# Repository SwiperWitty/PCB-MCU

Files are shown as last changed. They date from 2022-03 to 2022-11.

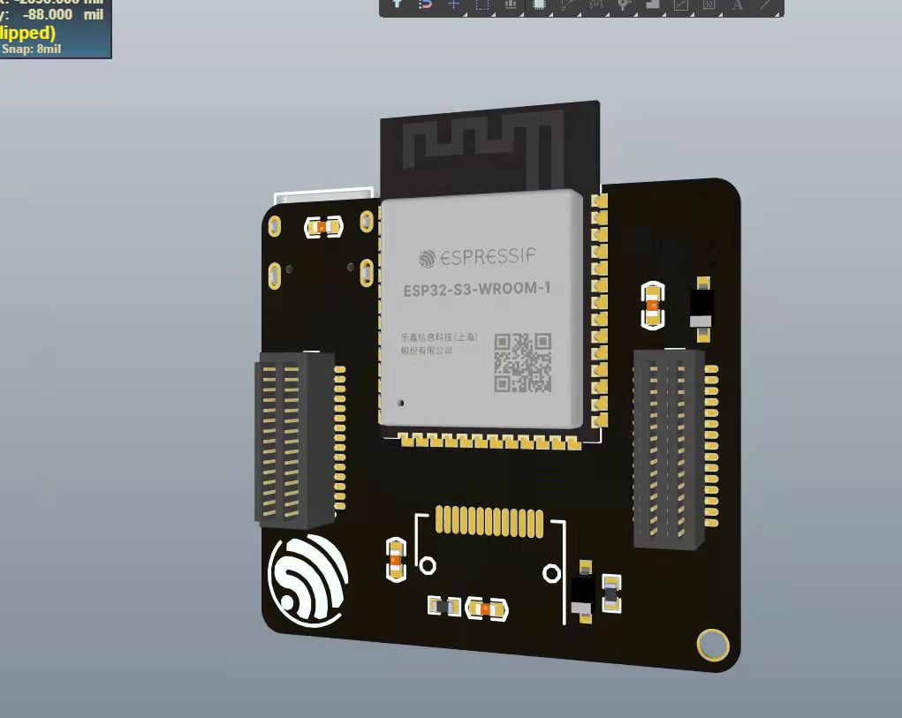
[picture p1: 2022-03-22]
ESP32-S3-HardWare/渲染/ad.jpg

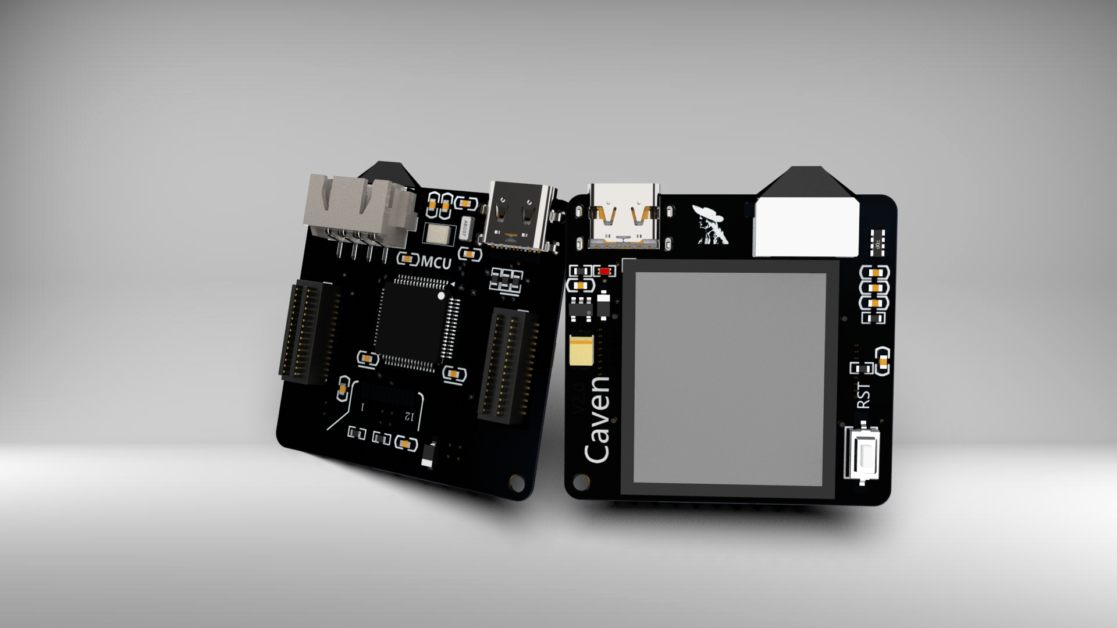
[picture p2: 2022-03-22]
Cavendish/渲染/Caven.jpg

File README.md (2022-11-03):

# PCB-MCU

**MCU-Core board**

# Cavendish(卡文迪许)

STM32 -> 3.0 & 3.14 CORE Software in [here](https://github.com/SwiperWiity/Core-STM32) !

- ##  STM32

#### STM32F103RCT6/GD32

##### Cavendish-ARM	V2.0

Caven

##### Cavendish-ARM	V3.0



##### Cavendish-ARM	V3.14



#### STM32F405RET6

Same as above !

- ## ESP32

#### ESP32-S3

Cavendish-ESP	V1.0



# other：

## PCB-C51



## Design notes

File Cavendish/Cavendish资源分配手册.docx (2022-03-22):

# Cavendish 硬件资源分配手册V2.0

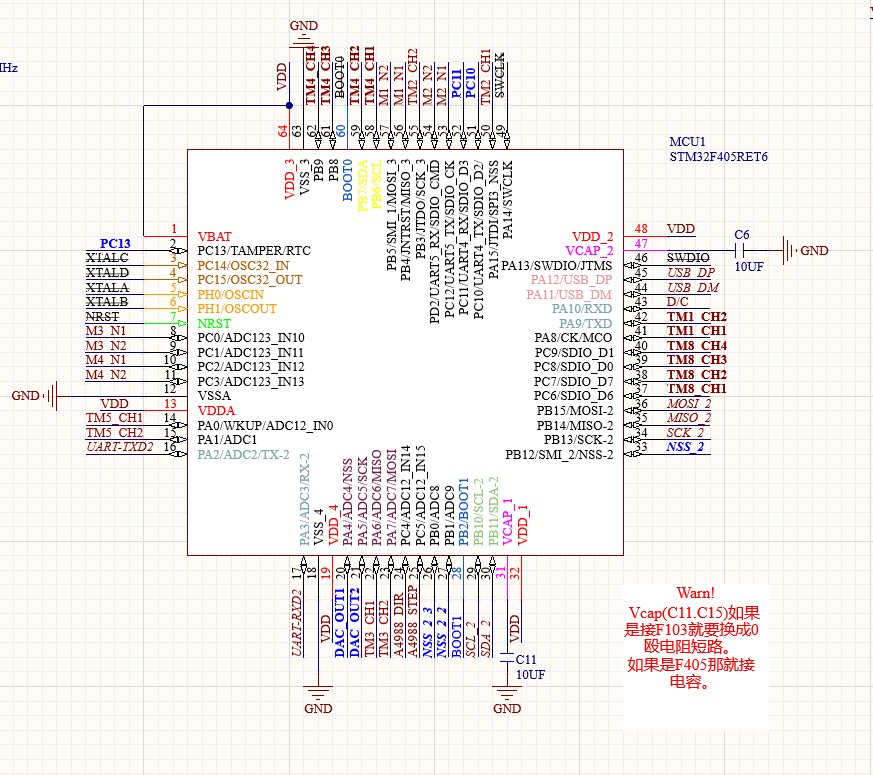
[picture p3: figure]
4f4f9511edc25ea571e4639c8b510fe
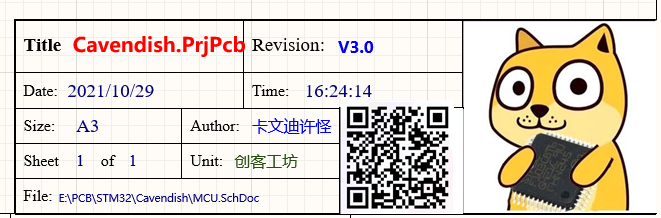
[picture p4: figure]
b53caab79645a7834c044930e13f0a2

目录

Cavendish 硬件资源分配手册V2.0 1

1. LCD 3

2. KEY 5

3. TIME 6

4. UART 8

5. SPI 9

6. USB 10

7. I2C 11

8. ADC 12

9. DAC （和ADC共用） 13

10. 步进电机 14

11. 电机组合 15

## Cavendish STM32F103RCT6/RBT6

### 1. LCD

硬件设备LCD，使用硬件的SPI2，其中：

PA10(D/C) PB12(CS) PB13(SCLK) PB15 (MOSI)

以上GPIO均不可除LCD功能以外使用！（CS可以极限驱动73HC595）

#### 1. RES

不占用GPIO,使用硬件上电复位（需要在MCU上电后等待20MS）

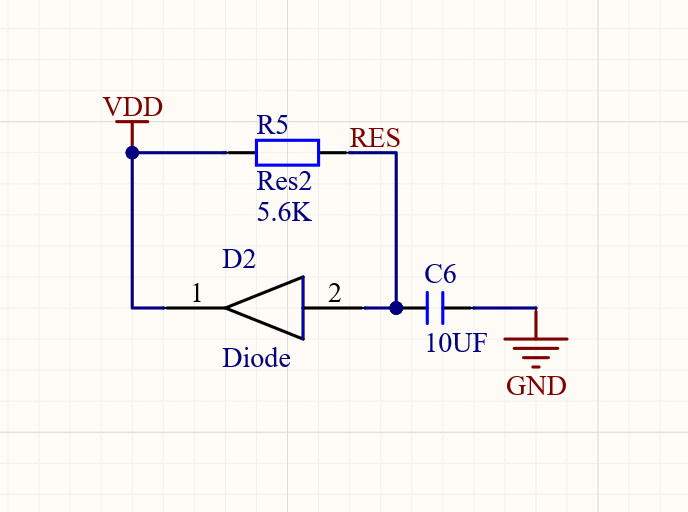
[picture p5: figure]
cd68124e201493866216ad20c528cc5

#### 2. SPI_CS(NSS-2)

PB12

#### 3. SPI_SCL(SCK-2)

PB13

#### 4. SPI_DC（未引到Pin）

PA10(占用UART1的RXD)，所以本设计如果要使用UART1需要重映射。

#### 5. SPI_MOSI

PB15

### 2. KEY

#### KEY0

PC13 触摸按键

#### 自由IO

PC10

PC11

### 3. TIME

#### 1. PWM

通常使用TIM1和TIM8高级定时器做为PWM基础时钟。

##### TIM4

通常作为控制舵机的PWM。

PB6 Channel 1

PB7 Channel 2

PB8 Channel 3

PB9 Channel 4

##### TIM8

通常为直流有刷电机调试PWM。

PC6 Channel 1

PC7 Channel 2

PC8 Channel 3

PC9 Channel 4

#### 2. Capture(编码器)

一般用在读取电机转速、编码按键（相当于鼠标）

##### TIM1

PA8 Channel 1

PA9 Channel 2

##### TIM2

PA15 Channel 1

PB3 Channel 2

##### TIM3

PA6 Channel 1

PA7 Channel 2

##### TIM5

PA0 Channel 1

PA1 Channel 2

### 4. UART

#### 1. 串口2

PA2 TXD

PA3 RXD

#### 2. 串口3 重映射（串口4）

PC10 TXD

PC11 RXD

### 5. SPI

只提供SPI2：

PB15 MOSI

PB14 MISO

PB13 SCLK

PB12 NSS (LCD)

PB1 NSS2

PB0 NSS3 (BZZ)

### 6. USB

PA11 USB_DM

PA12 USB_DP

### 7. I2C

只有I2C-2，有时也用于超声波（需要改接口）

PB11 SDA

PB12 SCL

### 8. ADC

PA4 ADC4

PA5 ADC5

### 9. DAC （和ADC共用）

PA4 OUT1

PA5 OUT2

### 10. 步进电机

DIR PC4

STEP PC5

### 11. 电机组合

#### 1. Motor 1

TIM8- Channel 1

编码 Tim2

方向控制 PB4 PB5(不分AB)

#### 2. Motor 2

TIM8- Channel 2

编码 Tim1

方向控制 PC12 PD2(不分AB)

#### 3. Motor 3（Only Reptile）

TIM8- Channel 3

编码 Tim3 (Type 底板为编码按键)

方向控制 PC0 PC1(不分AB)

#### 4. Motor 4（Only Reptile）

TIM8- Channel 4

编码 Tim5

方向控制 PC2 PC3(不分AB)

## Cavendish STM32F405RET6

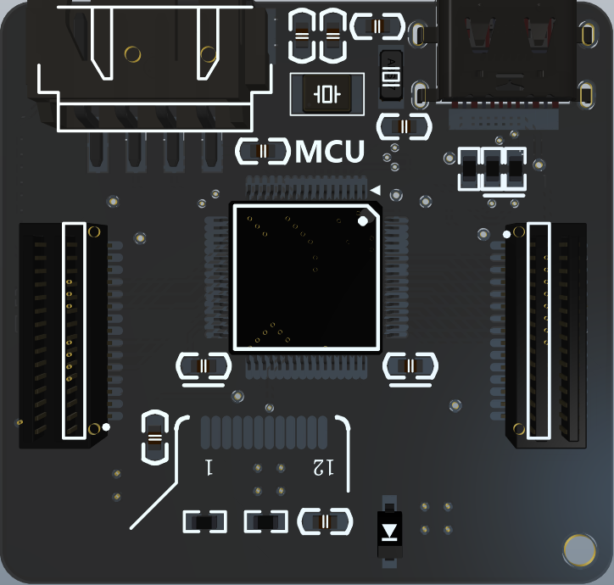
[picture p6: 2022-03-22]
Cavendish/渲染/back.png

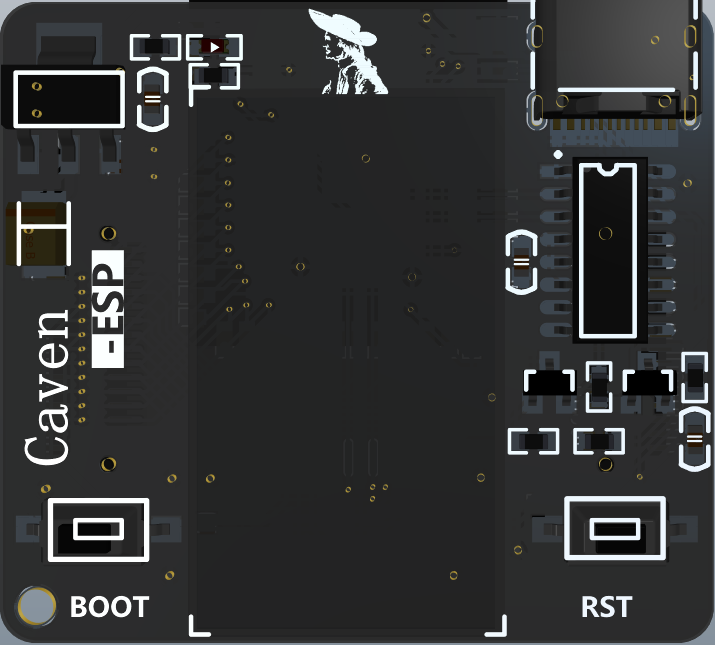
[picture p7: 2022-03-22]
ESP32-S3-HardWare/渲染/f.png

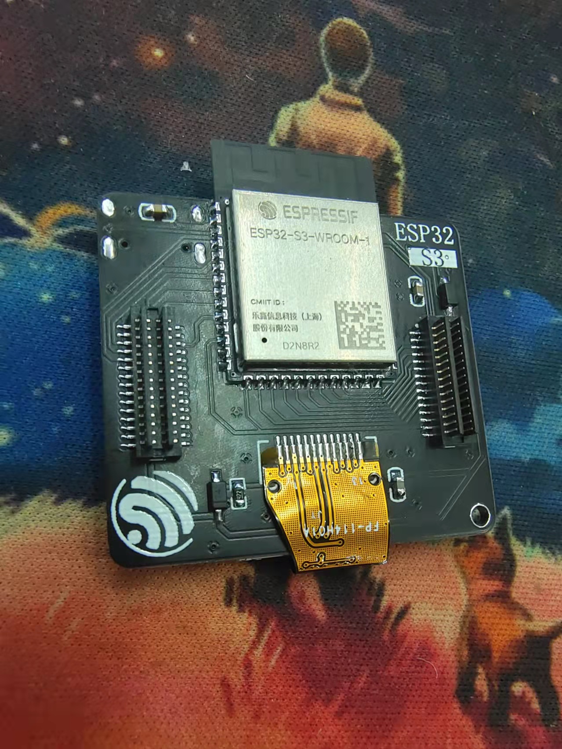
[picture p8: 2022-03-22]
ESP32-S3-HardWare/渲染/b.jpg

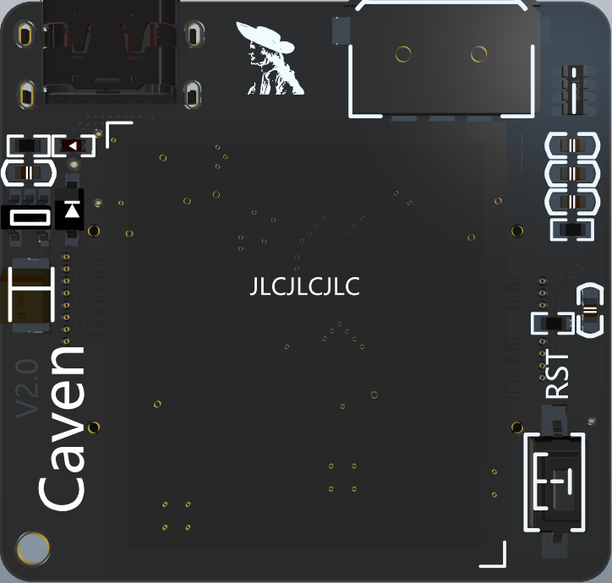
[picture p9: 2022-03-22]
Cavendish/渲染/frist.png

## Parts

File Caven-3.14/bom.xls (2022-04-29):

name |  |  |  |  |  |  |  |  |  |  |  | 0
Bill of Materials for PCB Document [Copy of PCB1.PcbDoc]
卡文迪许 |  |  |  |  |  |  |  |  | 联系方式：13226348320
test 2022-04-24 (49-/-54)
序号 | 器件 | 封装 | 单机用量 | 位号 | 型号 |  | 规格描述 | 总用量 |  | 单价 | 趋势 | 小计
# | Comment | Footprint | Quantity | Designator | Description |  | taobao | NUM
1 | 100NF | CAP_0603 | 6 | C1, C2, C6, C7, C13, C15 | CAP 12~50V | _ |  |  |  |  |  | 0
2 | 100UF | CAP_3216_A | 2 | C3, C4 | CAP 6~12V 钽电容 | _ |  |  |  |  |  | 0
1 | 10UF | CAP_0603 | 2 | C5, C8 | CAP 12~50V | _ |  |  |  |  |  | 0
2 | 10PF | CAP_0603 | 2 | C9, C10 | CAP 12~50V | _ |  |  |  |  |  | 0
1 | 22PF | CAP_0603 | 3 | C11, C12, C14 | CAP 12~50V | _ |  |  |  |  |  | 0
2 | 4.7UF | CAP_0603 | 1 | C16 | CAP 12~50V | _ |  |  |  |  |  | 0
1 | Type-C | USB-TYPE-C_16A | 1 | COM1 | USB | _ |  |  |  |  |  | 0
2 | B5819W | DIODE_SOD123 | 1 | D1 | Diode_肖特基/二极管 | _ |  |  |  |  |  | 0
1 | 1N4148 | DIODE_SOD123 | 1 | D2 | Diode_肖特基/二极管 | _ |  |  |  |  |  | 0
2 | FUSE | Fuse_0603 | 1 | F1 | FUSE | _ |  |  |  |  |  | 0
1 | 31PIN | BTB-DM3-31P | 2 | J1, J2 | BTB | _ |  |  |  |  |  | 0
2 | KEY | KEY_SMD | 1 | K1 | Key | _ |  |  |  |  |  | 0
1 | LED_R/G/B/Y | LED_0603_R | 1 | LED1 | LED | _ |  |  |  |  |  | 0
2 | STM32F405RET6 | LQFP_64_10X10 | 1 | MCU1 | MCU | _ |  |  |  |  |  | 0
1 | 10K | RESC_0603_2 | 3 | R1, R5, R6 | RES 贴片 | _ |  |  |  |  |  | 0
2 | 5.1K | RESC_0603_2 | 2 | R2, R3 | RES 贴片 | _ |  |  |  |  |  | 0
1 | 20R | RESC_0603_2 | 1 | R7 | RES 贴片 | _ |  |  |  |  |  | 0
2 | 4.7K | RESC_0603_2 | 1 | R8 | RES 贴片 | _ |  |  |  |  |  | 0
1 | SPX3819M5-L | SOT23_5 | 1 | U1 | DC-DC 3.3V 500ma | _ |  |  |  |  |  | 0
2 | CH549F | QFN28_4X4_L | 1 | U2 | MCU | _ |  |  |  |  |  | 0
1 | TTP223 | SOT-23-6 | 1 | U3 | 触摸芯片 | _ |  |  |  |  |  | 0
2 | TFT_1.3_12Pin | LCD_1.3B | 1 | U4 | ST7789V-SPI | _ |  |  |  |  |  | 0
1 | 32KHz | XTAL_SMD_3215 | 1 | Y1 | CRYSTAL | _ |  |  |  |  |  | 0
2 | 8MHz | XTAL-SMD5032-2P | 1 | Y2 | CRYSTAL | _ |  |  |  |  |  | 0
4 | PCB |  |  |  |  |  |  |  |  |  |  | 0
 |  |  |  | 货币 | CNY | 税率 |  | 购买套数 | 单板总价 |  | 合计总价 | 0
 |  |  |  |  |  |  | 制表：卡文迪许

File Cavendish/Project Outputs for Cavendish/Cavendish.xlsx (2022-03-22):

Comment | Description | Designator | Footprint | LibRef | Quantity
100NF | CAP 12~50V, CAP | C1, C2, C3, C4, C5, C7, C8 | CAP_0603 | CAP, CAP_SDM | 7
100UF | CAP 6~12V 钽电容 | C6 | CAP_3528_B | CAP_TA | 1
10PF | CAP | C9, C10 | CAP_0603 | CAP_SDM | 2
10UF | CAP | C11, C15 | CAP_0603 | CAP_SDM | 2
22PF | CAP | C12, C13 | CAP_0603 | CAP_SDM | 2
4.7uF | CAP | C14 | CAP_0603 | CAP_SDM | 1
Type-C | USB | COM1 | USB-tYPE_C_C | USB-type_c | 1
Diode_SMA | Diode_肖特基 | D1 | DIODE_SOD123 | Diode-SM | 1
Diode | 开关二极管 | D2 | SOD123 | Diode-SOD | 1
P4 |  | J1 | XH2.54-WS-4P | SWD | 1
30PIN |  | J2, J3 | BTB_Double_30Pin_Up | BTB_DOUBLE_30PIN | 2
key | Key | K1 | KEY-A | key | 1
KEY | KEY | KEY1 | LY-K3 | LY-K3 | 1
LED_R/G/B/Y | LED | LED1 | LED_0603_R | LED | 1
STM32F405RET6 | MCU | MCU1 | LQFP_64_10X10 | STM32f4_R | 1
1.5K | RES 贴片 | R1 | RESC_0603_2 | RES_S | 1
22R | RES 贴片 | R2, R3 | RESC_0603_2 | RES_S | 2
10K | RES 贴片 | R4, R5 | RESC_0603_2 | RES_S | 2
10K | RES | R6 | RESC_0603_4 | RES_P4 | 1
2K | RES 贴片 | R7 | RESC_0603_2 | RES_S | 1
20R | RES 贴片 | R8 | RESC_0603_2 | RES_S | 1
4.7K | RES 贴片 | R9 | RESC_0603_2 | RES_S | 1
SPX3819M5-L | DC-DC 3.3V 500ma | U1 | SOT23_5 | SPX3819M5-L | 1
TFT_1.3_12Pin | ST7789V-SPI | U2 | LCD_1.3B | LCD_1.3 T | 1
32.768KHz | CRYSTAL | Y1 | XTAL_SMD_3215 | XTAL | 1
8MHz | CRYSTAL | Y2 | XTAL_3225 | XTAL | 1

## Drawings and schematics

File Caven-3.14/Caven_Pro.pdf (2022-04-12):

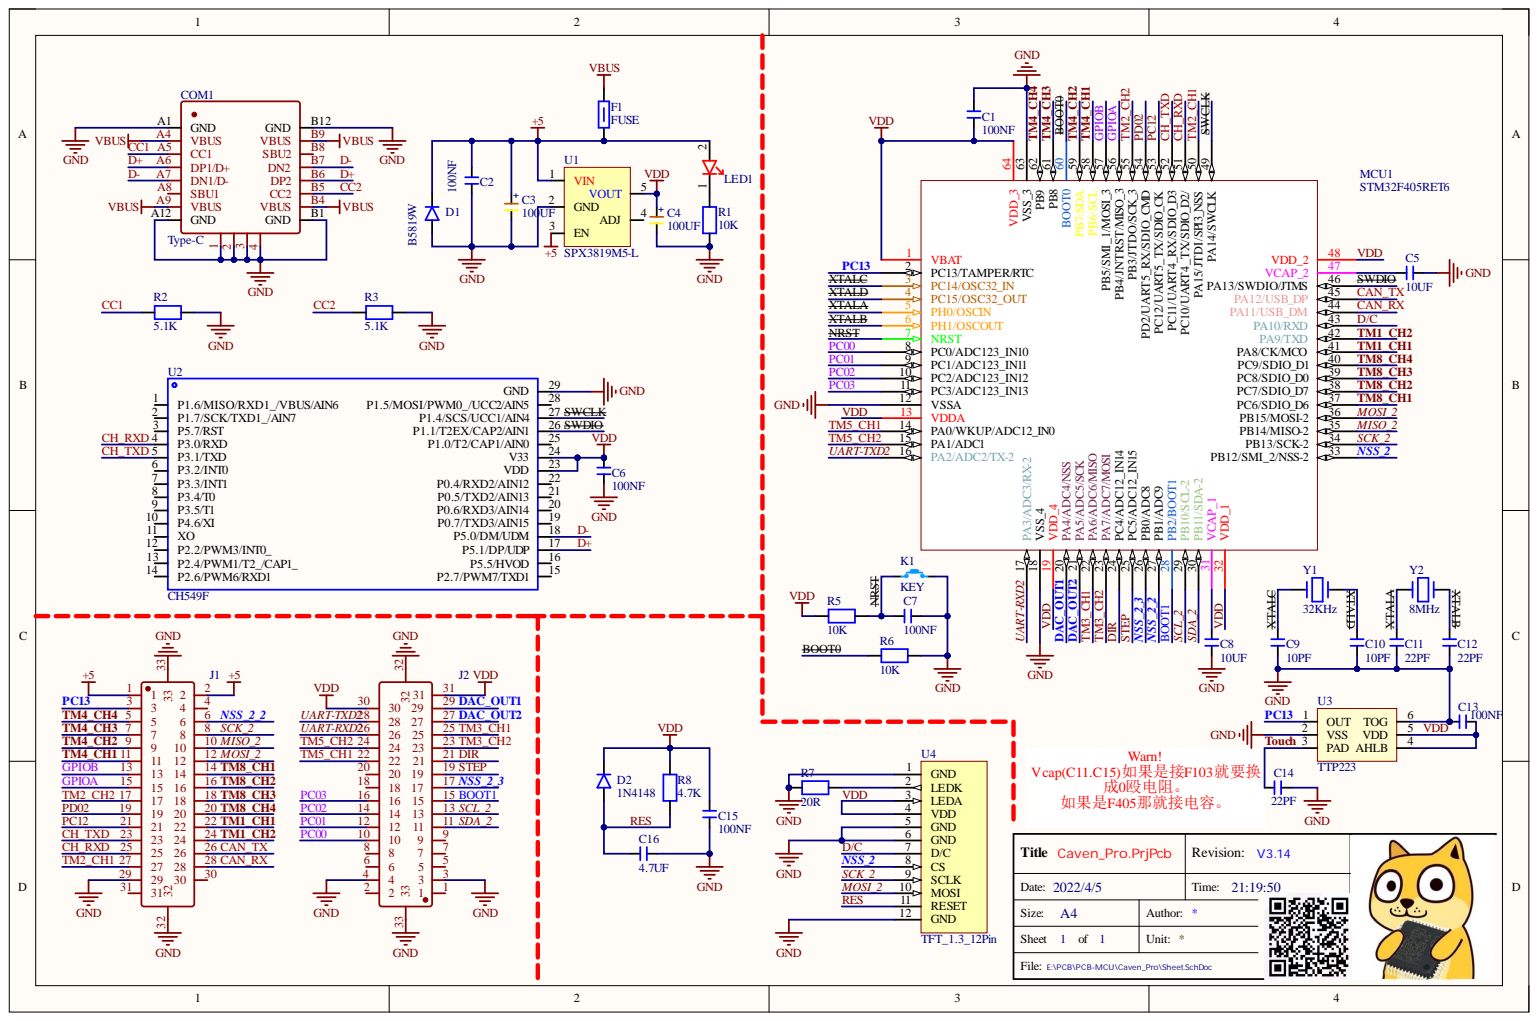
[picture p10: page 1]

PB3/JTDO/SCK_3 55 PB4/JNTRST/MISO_3 56 PB5/SMI_1/MOSI_3 57 PB6/SCL 58 PB7/SDA 59 BOOT0 60 PB8 61 PB9 62 VSS_3 63 VDD_3 64

VDD_1 32 PB12/SMI_2/NSS-2 33 PB13/SCK-2 34 PB14/MISO-2 35 PB15/MOSI-2 36

Warn! Vcap(C11.C15)如果是接F103就要换 成0殴电阻。 如果是F405那就接电容。 | C14

LEDK 2
LEDA 3
VDD 4
GND 5

Title Caven_Pro.PrjPcb | Revision: V3.14

File: E:\PCB\PCB-MCU\Caven_Pro\Sheet.SchDoc

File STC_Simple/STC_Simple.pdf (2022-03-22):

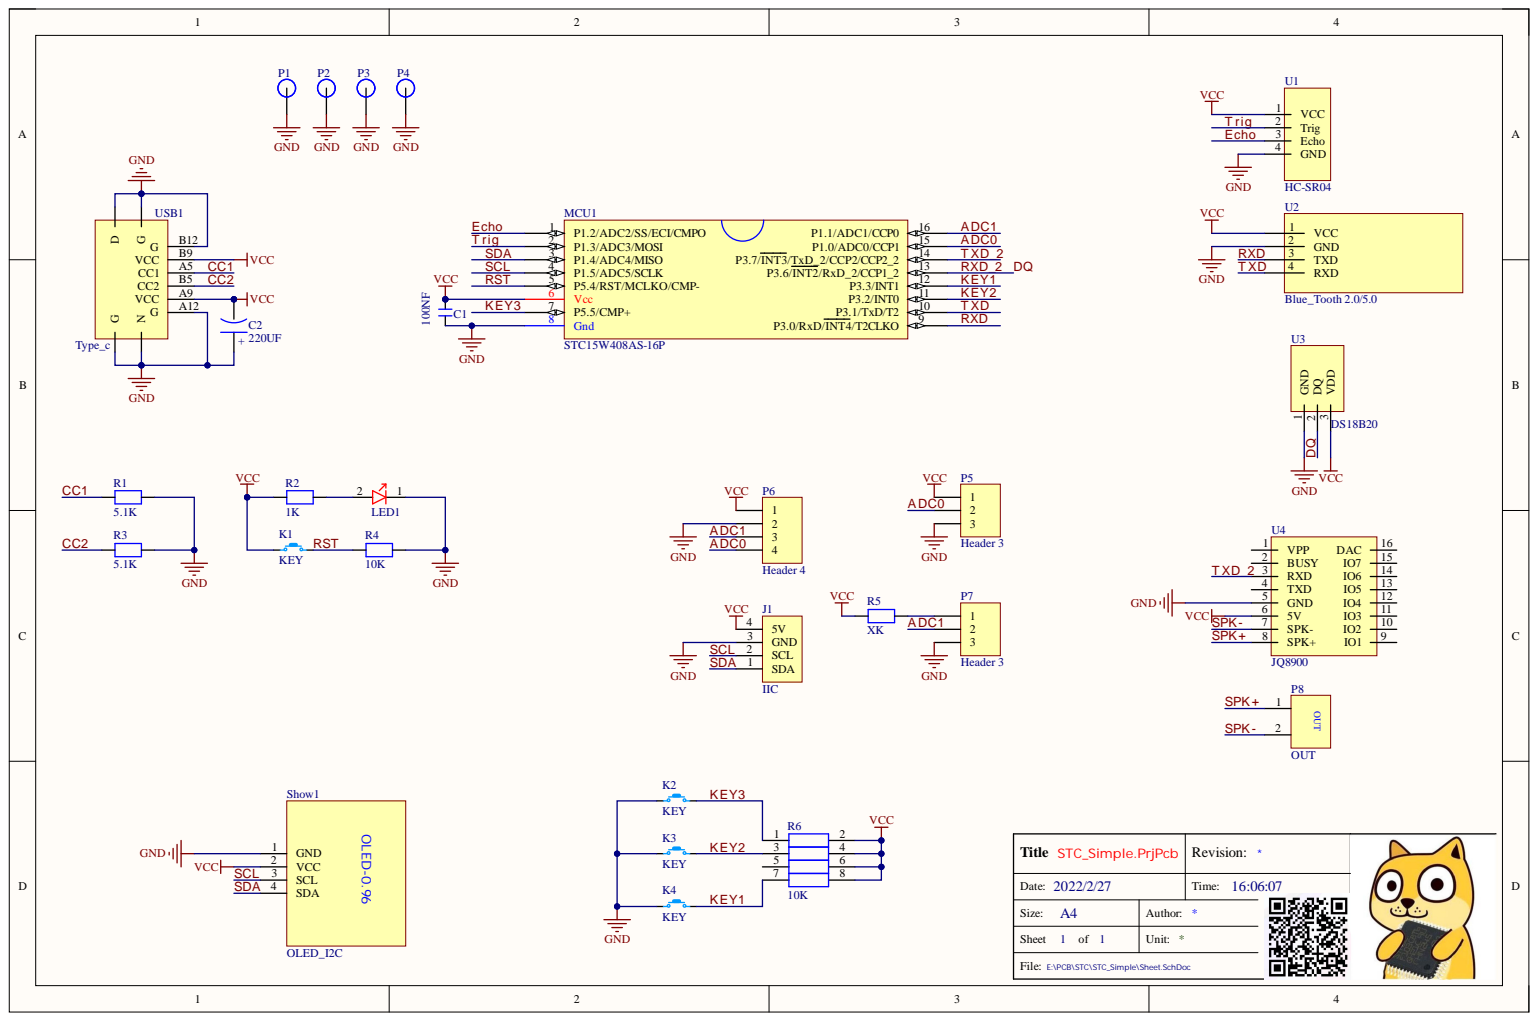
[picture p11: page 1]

Title STC_Simple.PrjPcb | Revision: *

File: E:\PCB\STC\STC_Simple\Sheet.SchDoc

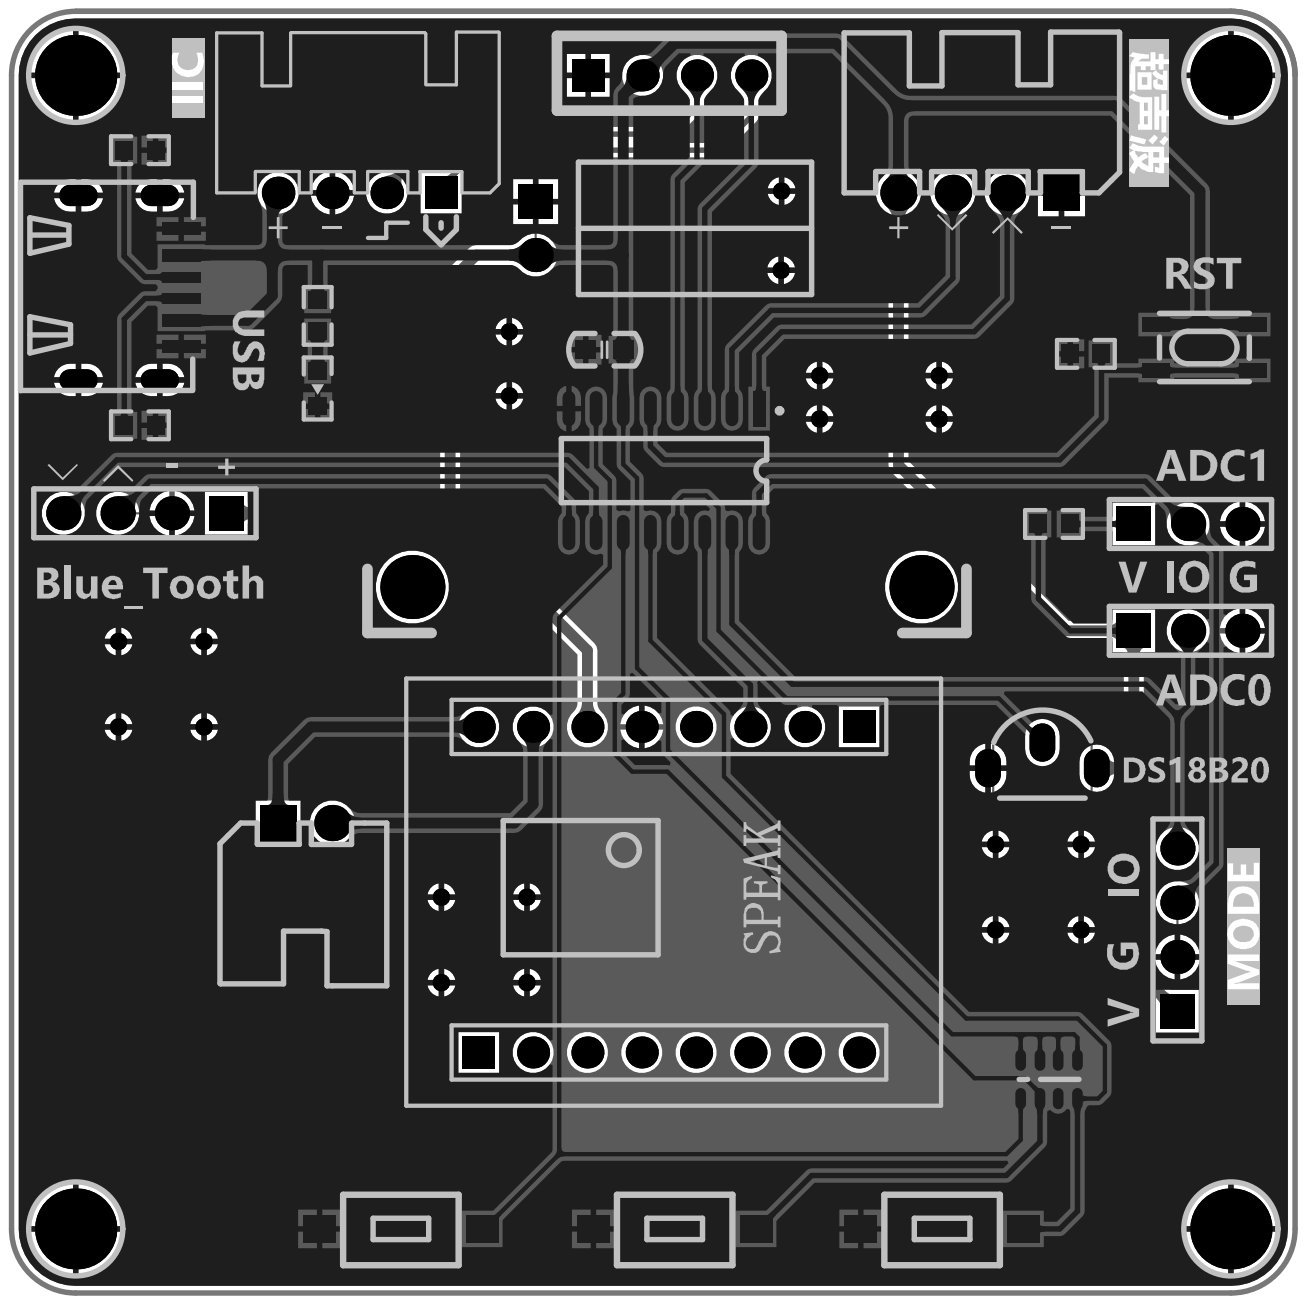
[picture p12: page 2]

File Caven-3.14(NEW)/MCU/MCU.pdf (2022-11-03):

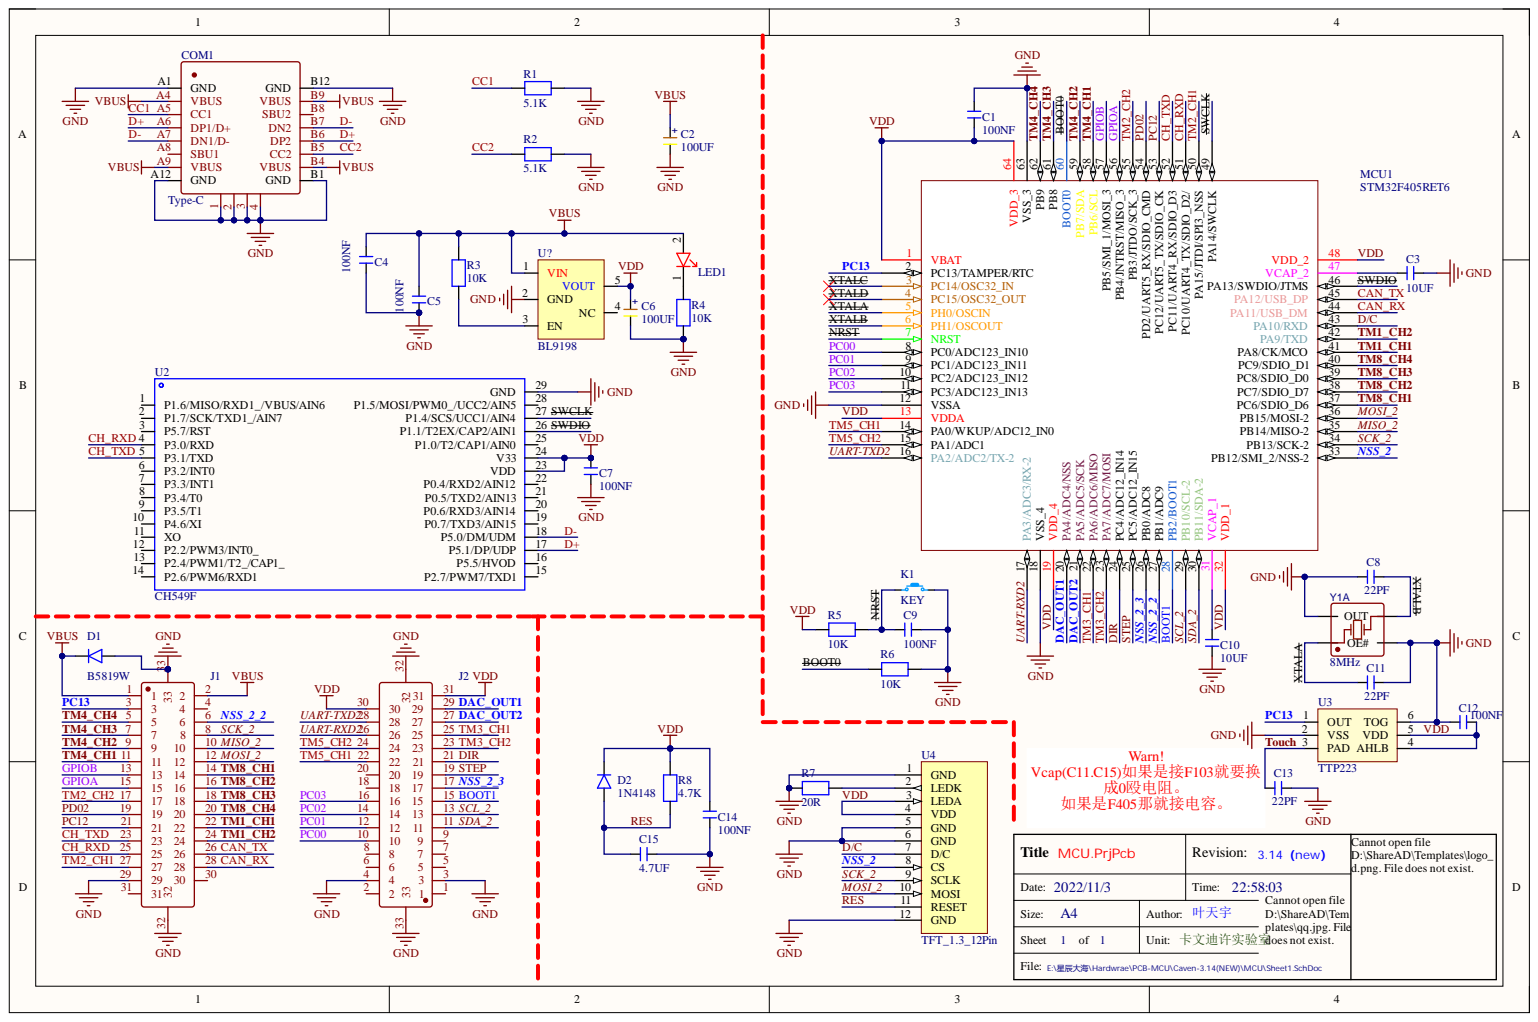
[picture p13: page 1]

PB3/JTDO/SCK_3 55 PB4/JNTRST/MISO_3 56 PB5/SMI_1/MOSI_3 57 PB6/SCL 58 PB7/SDA 59 BOOT0 60 PB8 61 PB9 62 VSS_3 63 VDD_3 64

VDD_1 32 PB12/SMI_2/NSS-2 33 PB13/SCK-2 34 PB14/MISO-2 35 PB15/MOSI-2 36

GND 5

Title MCU.PrjPcb | Revision: 3.14（new） | Cannot open file D:\ShareAD\Templates\logo_ d.png. File does not exist.

Cannot open file
D:\ShareAD\Tem
plates\qq.jpg. File
does not exist.

File: E:\星辰大海\Hardwrae\PCB-MCU\Caven-3.14(NEW)\MCU\Sheet1.SchDoc

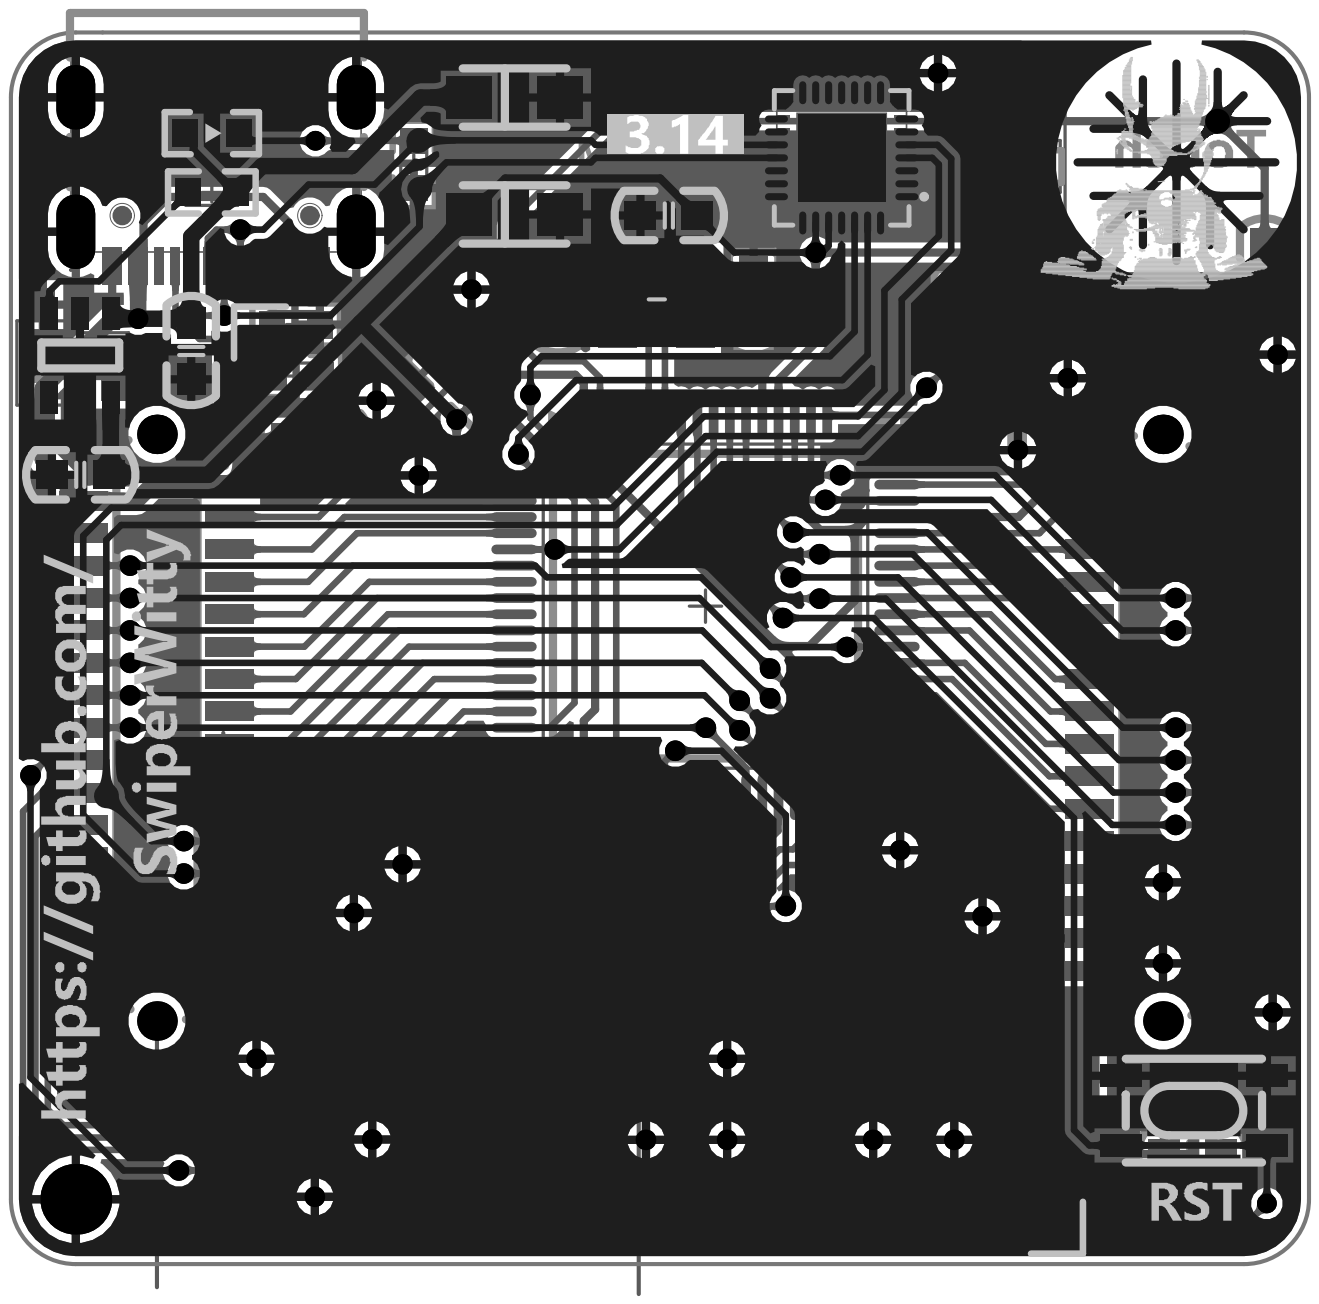
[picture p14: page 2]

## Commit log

2022-03-22 updata about pcb
    [Caven_Pro.PrjPcb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]
2022-03-22 updata cavendish v3.14 about ch549 error
    [Sheet.SchDoc]
2022-04-12 up 3.14
    [Caven_Pro.PrjPcb, Sheet.SchDoc]
2022-06-26 up new
    [MCU-3.14-NEW.GBL, MCU-3.14-NEW.GBO, MCU-3.14-NEW.GBP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]
